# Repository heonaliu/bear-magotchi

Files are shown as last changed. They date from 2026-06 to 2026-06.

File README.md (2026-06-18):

<div align="center">

# 🌸 Bearmagotchi

A custom bear-style case tamagotchi. Made by 17 y/o Heona Liu. This was my first full on hardware project, so I'm pretty proud of myself. Every step was a learning process: from KiCad interface, PCB routing, OnShape building, to coding with Arduino IDE for firmware and designing a zine.

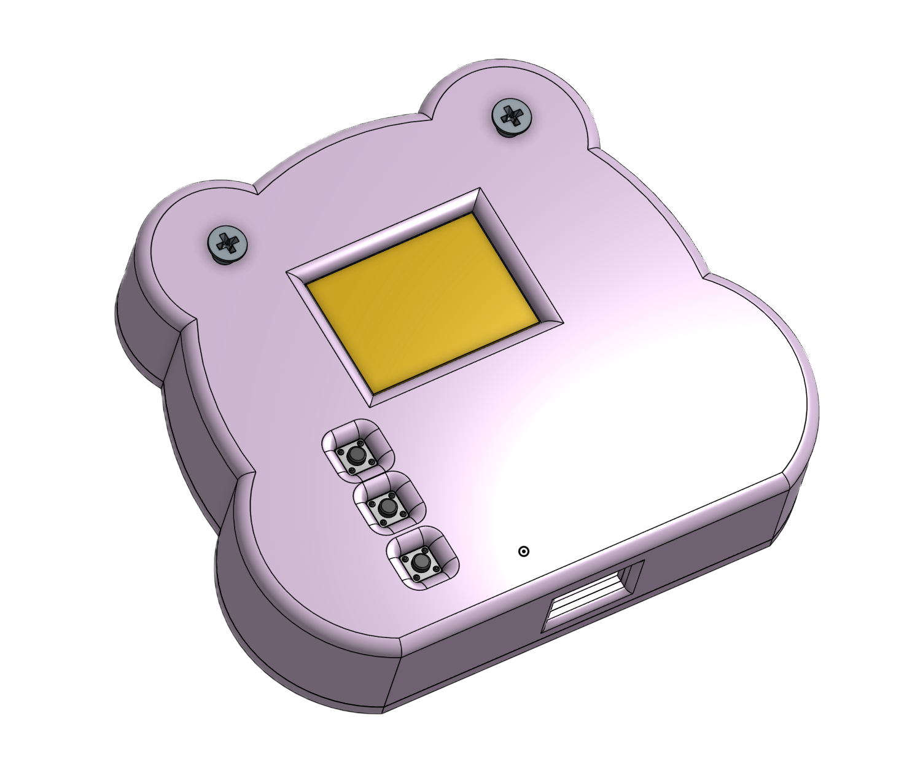
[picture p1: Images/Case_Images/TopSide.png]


This tamagotchi has 3 stats: hunger, energy, and happiness! You can play around with the different levels by using the buttons, each mapped to different functions. This was built by following [TaniWankenobi's](https://github.com/TaniWanKenobi) tamagotchi PCB tutorial. All 4 faces on the bearmagotchi are custom drawn!

## Why I Built This Project
I built this project because I have absolute 0 experience with hardware and wanted to learn! I find it so exciting to be able to design physical products! I'm more of a software person so working with hardware isn't easy for me. I procrastinated a lot because I was intimidated at first by hardware and its complexities, but I finally got the discipline and perseverance to start and finish this project. Throughout this project, I encountered many challenges and learning experiences, all which allowed me to further broaden my understanding of hardware and CAD. I also like cute things so this was a perfect project to build.

It took many trial and errors like learning how to solve DRC errors, rerouting, and being very confused at some points.

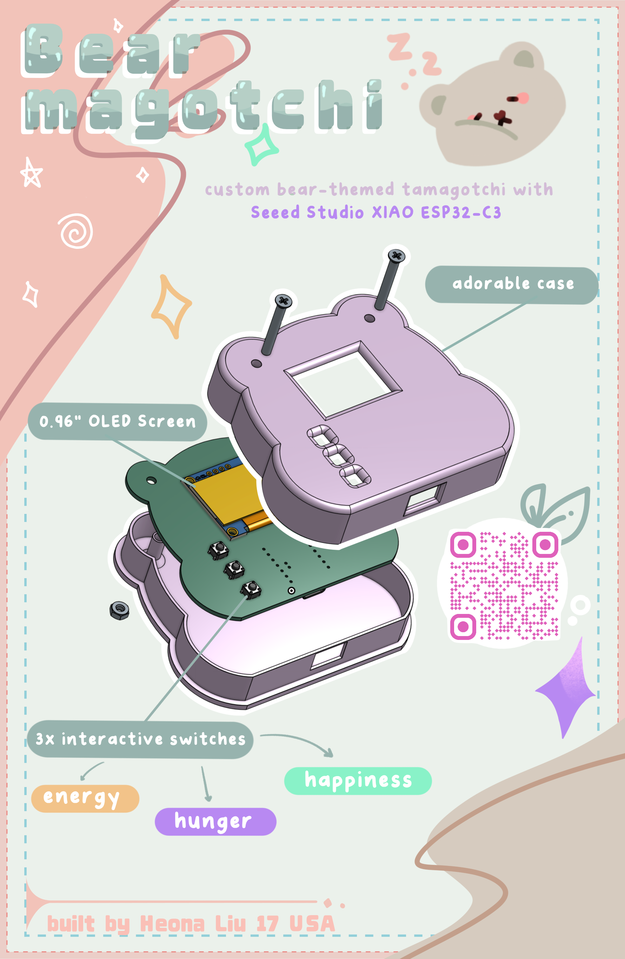
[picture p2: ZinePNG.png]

</div>

## Overview of how it works
Bearmagotchi was built with Seeed Studio XIAO ESP32-C3 and a custom PCB built with KiCad. OnShape was used to build the case design. Arduino IDE was used to code the button's functions with the OLED screen. There are three switches that you can press, which change the status of the pet's happiness, energy, and hungriness! 

### Key Parts Used:
- **Arduino MCU:** XIAO-ESP32-C3
- **Display:** 0.96" OLED screen
- **Power:** 3.7V rechargeable lithium polymer battery
- **Audio:** Buzzer -- [XHXDZ 1207-P6.5MM](https://www.lcsc.com/product-detail/C49246964.html)
- **Case:** Built with OnShape. View [Onshape CAD Link](https://cad.onshape.com/documents/021afe4b63c8b0b9c93cc183/w/f948377fc55dfd0736b0e217/e/5203c0fddfe92074836b1ae6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)
- **Firmware:** Arduino IDE in C++. Also wired and tested in a simulation in Wokwi.com. [Wokwi Link Here](https://wokwi.com/projects/467099855244316673)

- **Buzzer:** [XHXDZ 1207-P6.5MM](https://www.lcsc.com/product-detail/C49246964.html)
Switches: [BZCN TSC016A04518A](https://www.lcsc.com/product-detail/C2888493.html)
0.96" Oled Screen: [HS HS96L03W2C03](https://www.lcsc.com/product-detail/C5248080.html)

## Case Showcase
| **Top** | **Top Side View** |
| :--: | :--: |
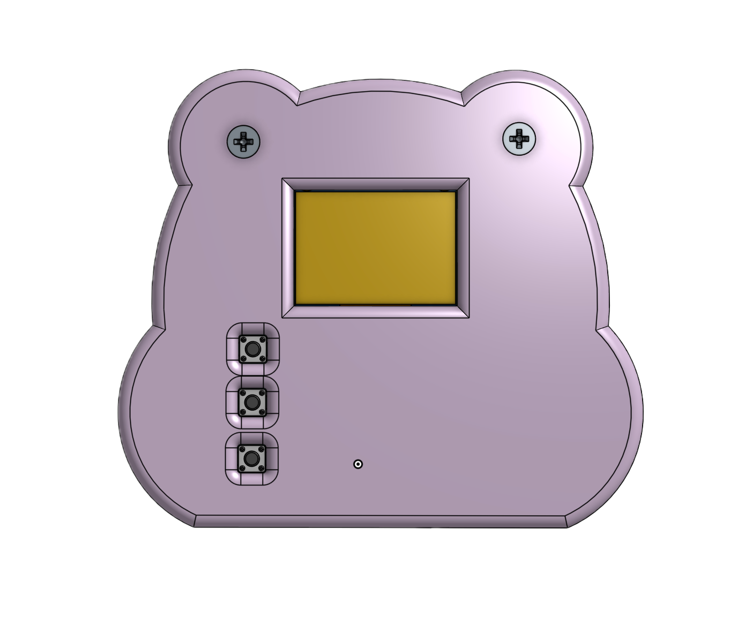
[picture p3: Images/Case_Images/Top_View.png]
|  | |
| **Bottom** | **Exploded View** |
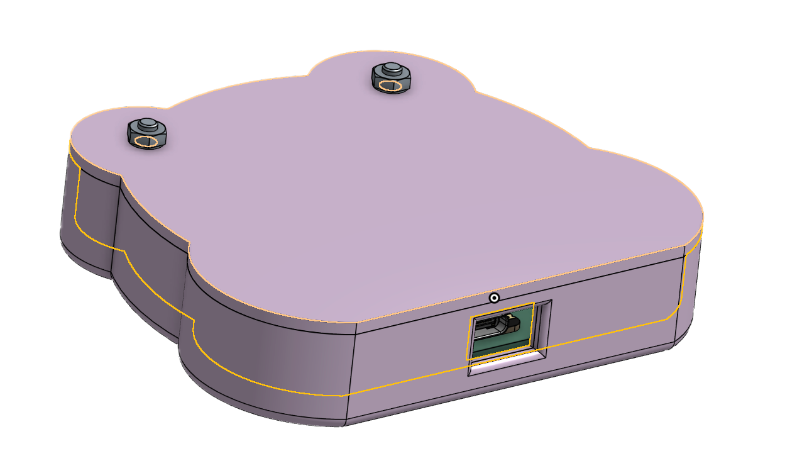
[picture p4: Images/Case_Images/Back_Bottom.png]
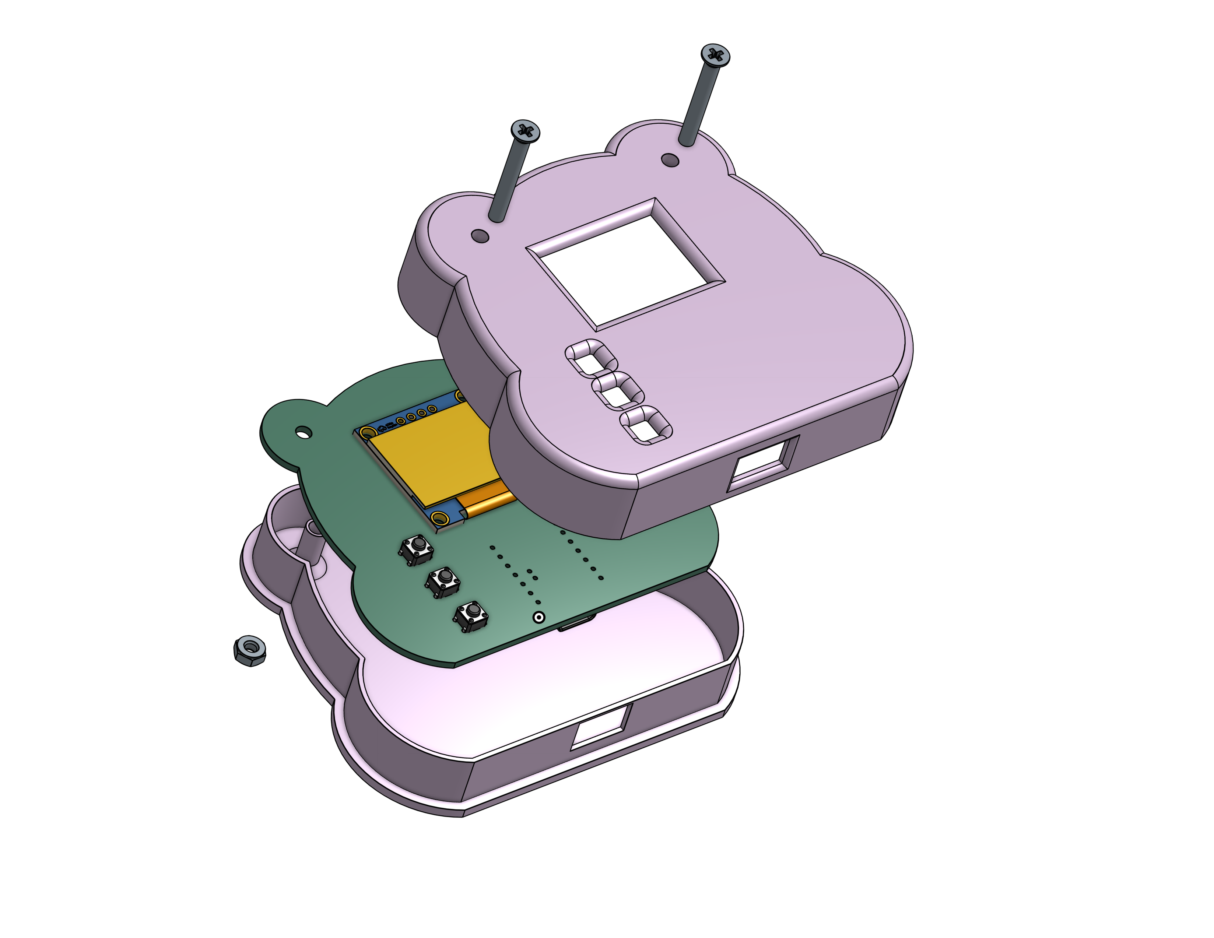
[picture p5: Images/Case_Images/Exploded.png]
|  | |

## PCB & Routing
| **Top** | **Top Routing Layer** |
| :--: | :--: |
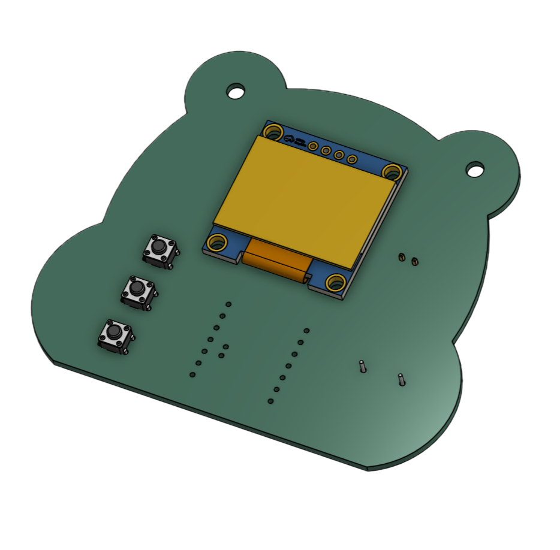
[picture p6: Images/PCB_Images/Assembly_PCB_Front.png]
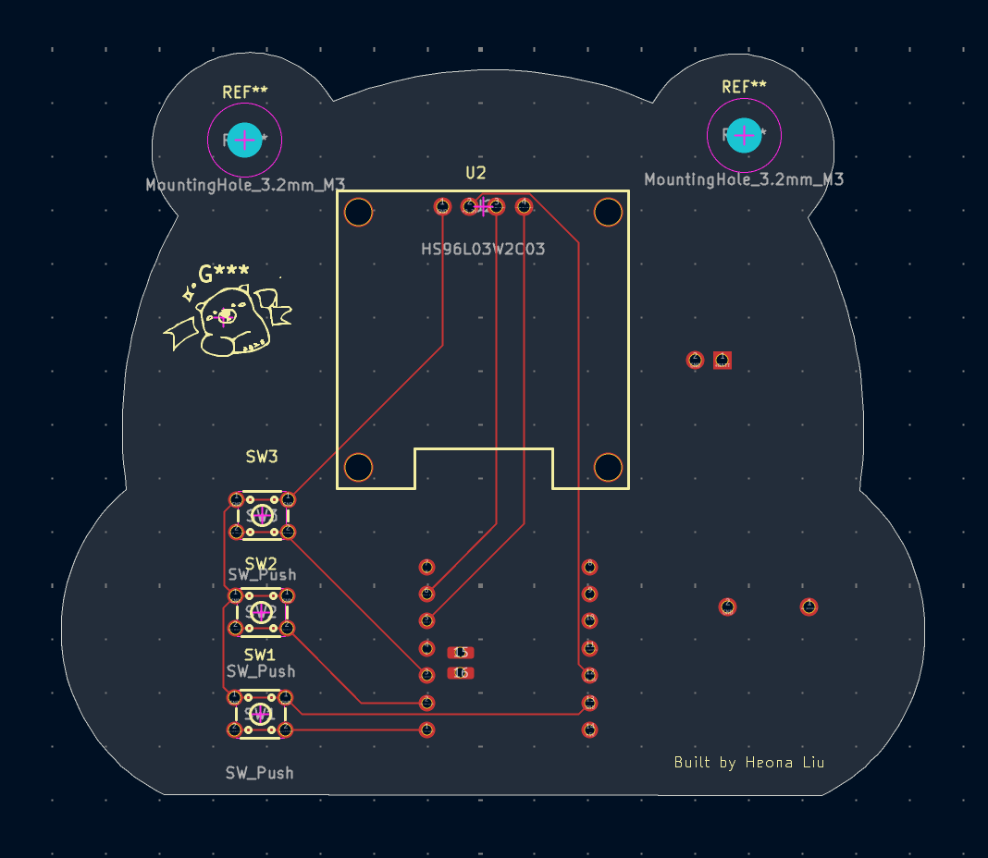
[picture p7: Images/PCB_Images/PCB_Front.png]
|  | |
| **Bottom** | **Bottom Routing Layer** |
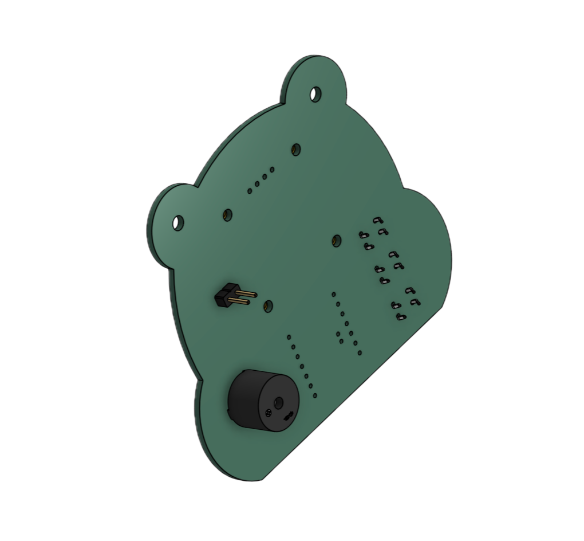
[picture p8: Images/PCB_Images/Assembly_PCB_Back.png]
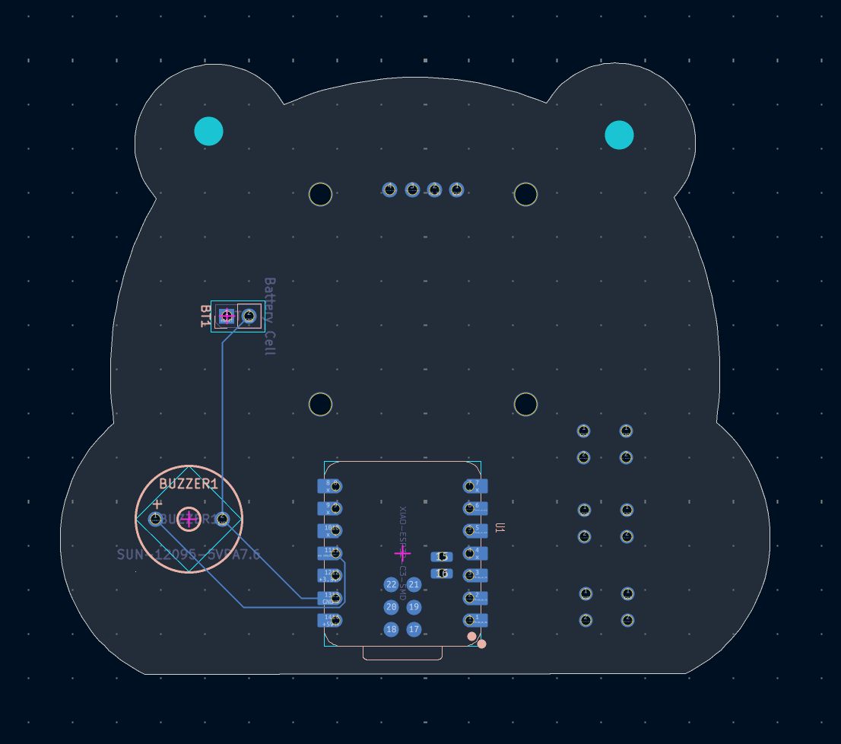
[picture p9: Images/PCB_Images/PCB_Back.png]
|  | |
|**Both**|
<div align="center">
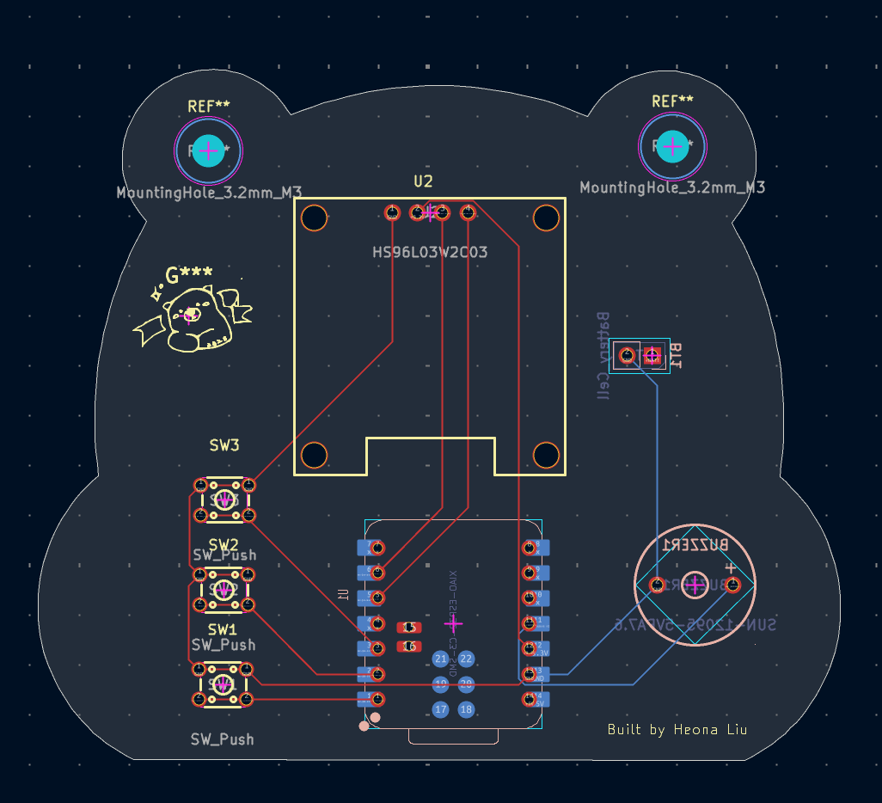
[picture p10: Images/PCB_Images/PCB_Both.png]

</div>

## Schematic
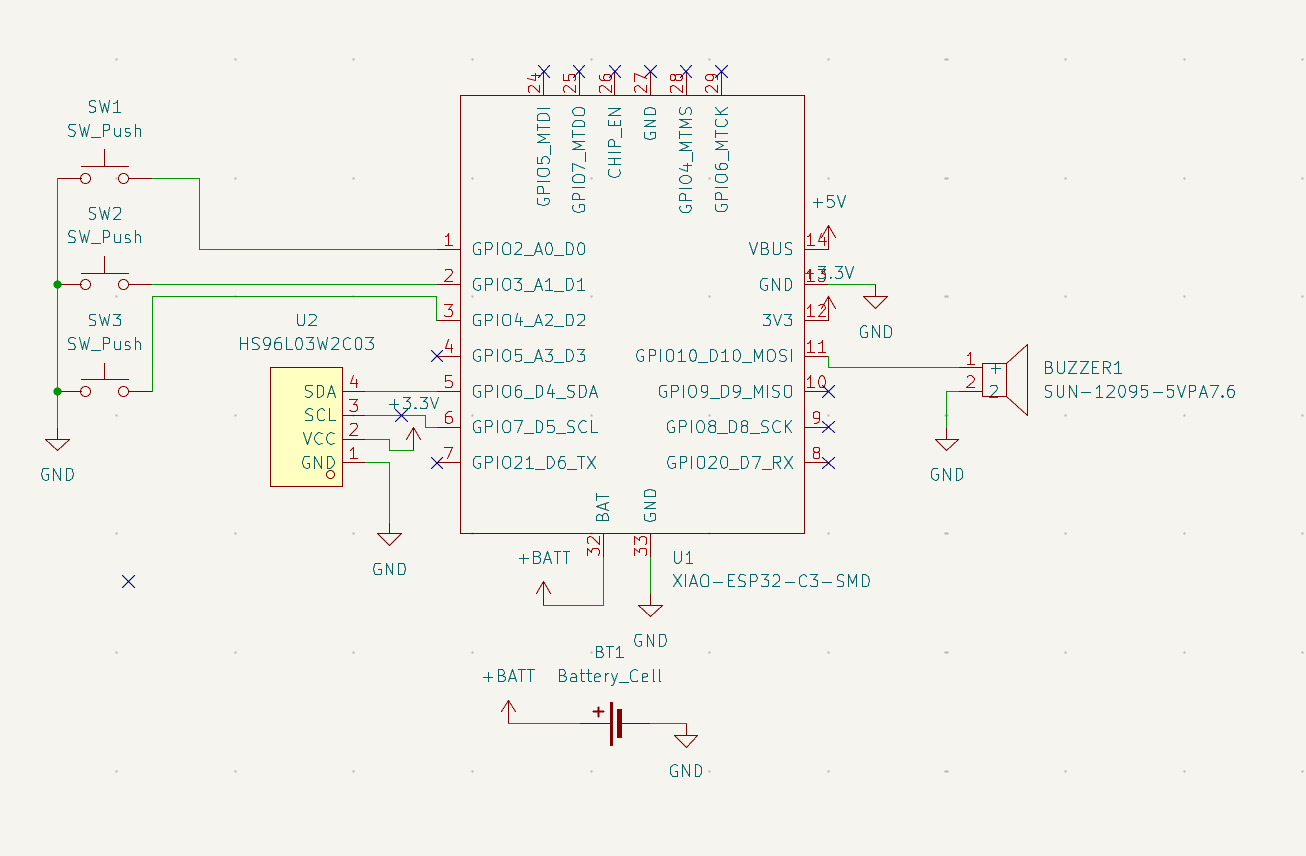
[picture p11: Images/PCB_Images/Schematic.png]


## Bill of Materials -- BOM:
| **Item** | **Description** | **Value** | **LCSC Part** | **Qty** | **MOQ** | **Total Price** | **Links** |
| :--: | :--: | :--: | :--: | :--: |:--: |:--: | :--: |
| Battery | Cell battery to power | Battery_Cell | -- | 1 | 1 | $3.37 | [Purchase Link](https://www.aliexpress.us/item/3256805856928609.html?gatewayAdapt=glo2usa4itemAdapt)
| Buzzer | Buzzer for audio | 1207-P6.5MM | C49246964 | 1 | 10 | $0.57 | [Purchase Link](https://www.lcsc.com/product-detail/C49246964.html)
| Switch | Push button | TSC016A04518A | C2888493 | 3 | 50 | $0.54 | [Purchase Link](https://www.lcsc.com/product-detail/C2888493.html)
| OLED Display | 0.96" OLED | HS96L03W2C03 | C5248080 | 1 | 1 | $2.25 | [Purchase Link](https://www.lcsc.com/product-detail/C5248080.html)
| Seeed Studio ESP32-C3 MCU | MCU Arduino board | XIAO-ESP32-C3-SMD | -- | 1 | 1 | $4.54 | [Purchase Link](https://www.aliexpress.us/item/3256806793530218.html?gatewayAdapt=glo2usa4itemAdapt)
| PCB | Main board for building | -- | -- | 1 | 1 | $4.00 | --
|PCB Shipping | To UPS Account | -- | -- | -- | -- | $2.50 | --
| **Total** |  |  |  | **8** | **64** | **$17.77** | |

## Structural (Screws, Nuts) -- BOM:
| **Item** | **Description** | **Qty**  | **Total Price** | **Link**
| :--: | :--: | :--: | :--: |:--: |
| M3 x 25mm Screw | PH Countersunk flat head screw M3x0.5 x 25 Stainless Steel  | 2 | $1.74 | [Purchase Link](https://accu-components.com/us/countersunk-socket-head-screws/5430-SSK-M3-25-A2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) |
| Hex Nut Grade A&B | M3x0.5  Stainless Steel  | 2 | $0.14 | [Purchase Link](https://belmetric.com/hex-nut-a2-stainless-din-934/?sku=NR3SS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) |
| Total | | 4 | $1.88 | |

## Step by Step Assembly
| **Bottom case** | **Place PCB on top** |
| :--: | :--: |
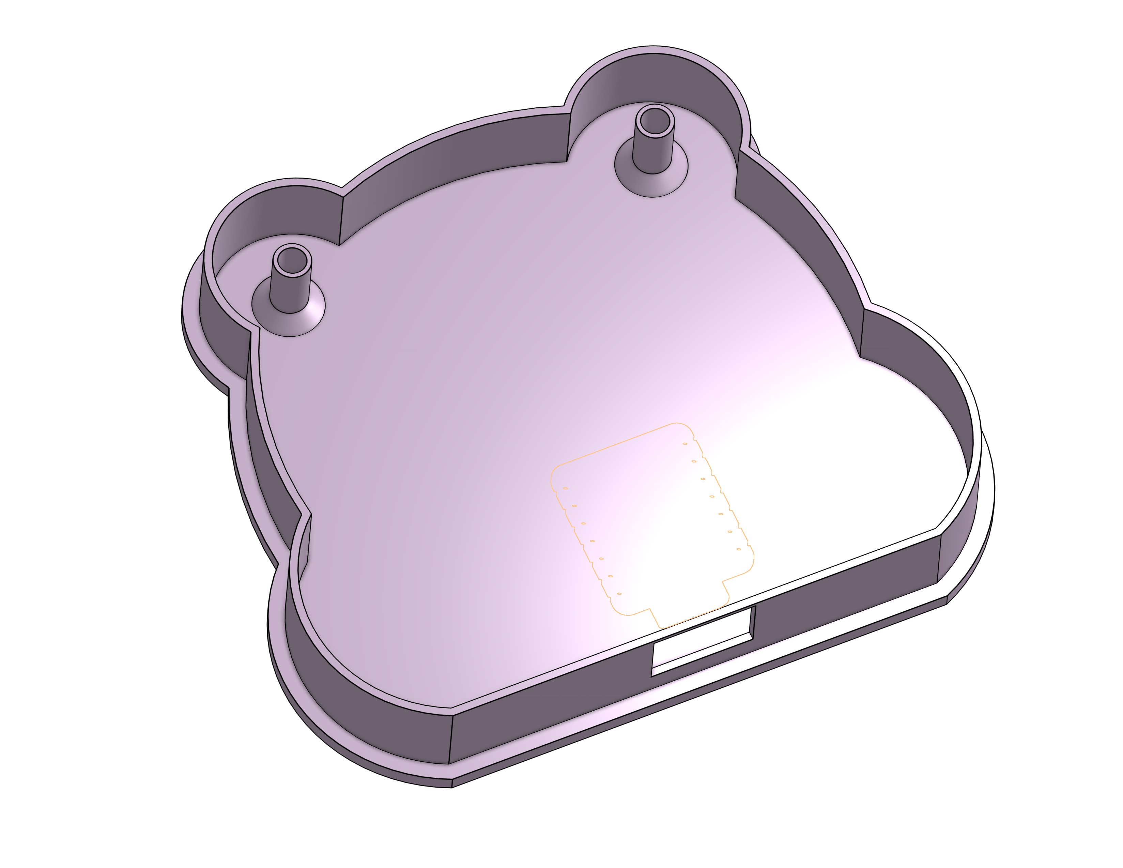
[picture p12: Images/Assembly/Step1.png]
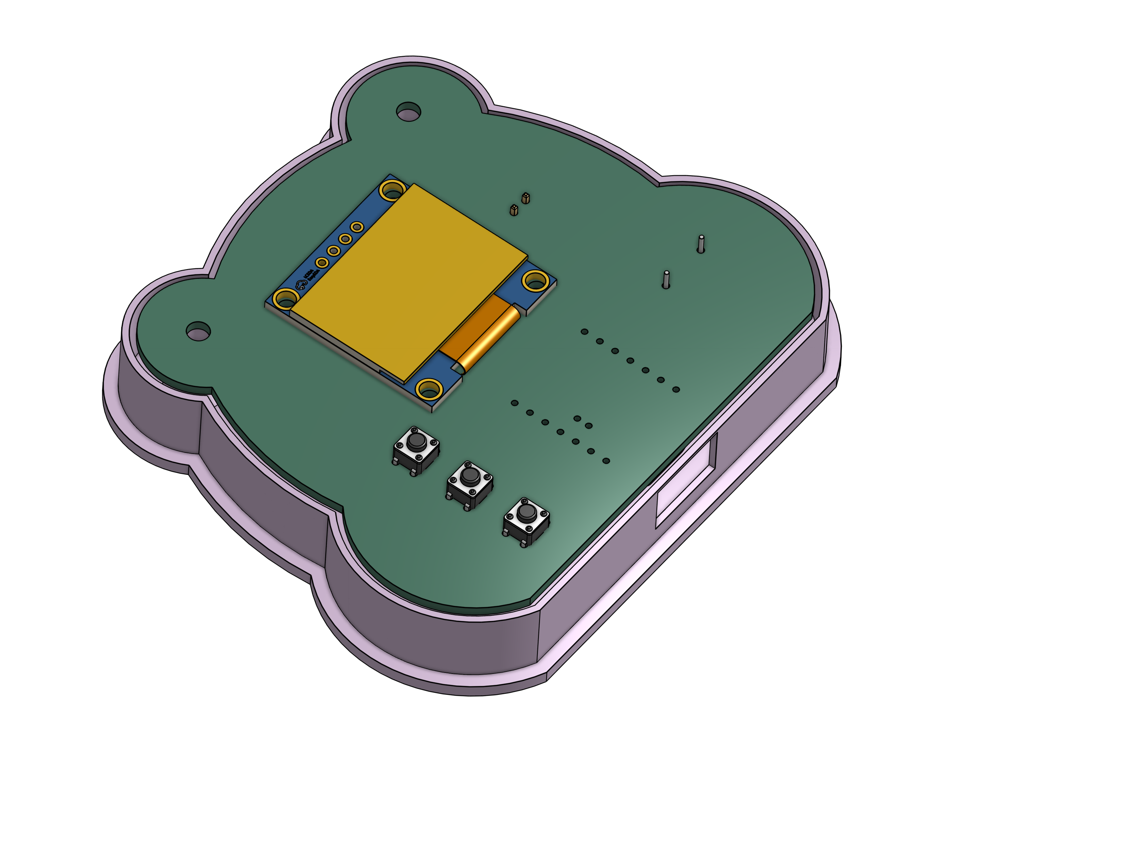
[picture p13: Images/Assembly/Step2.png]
|  | |
| **Place top cover aligned with the holes** | **Put in the M3 Screws & fasten with hex nuts** |
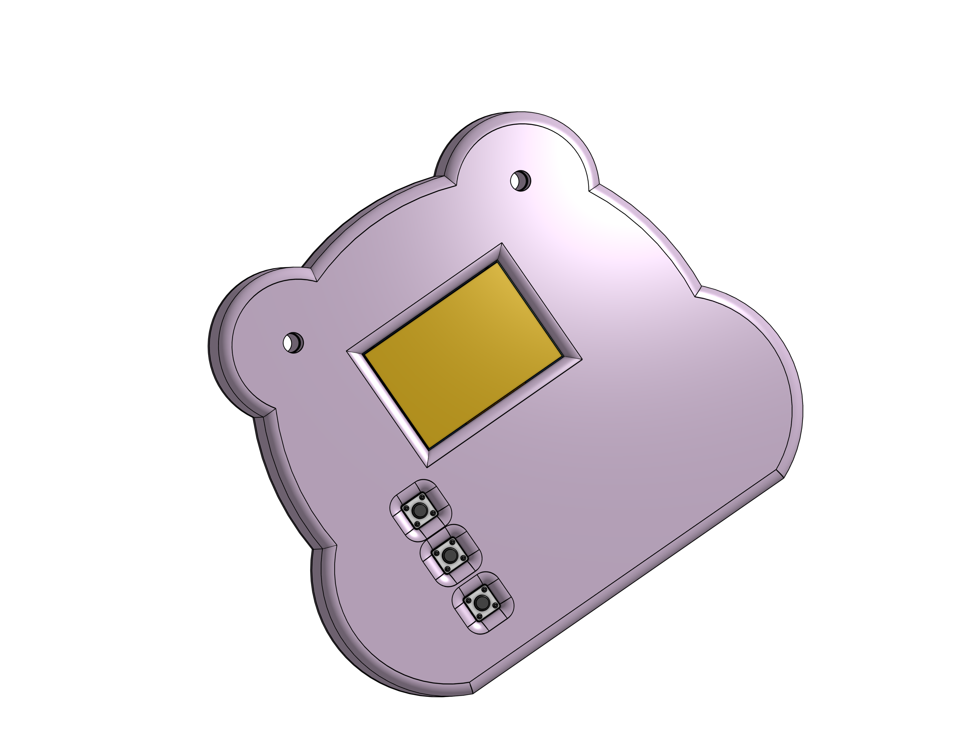
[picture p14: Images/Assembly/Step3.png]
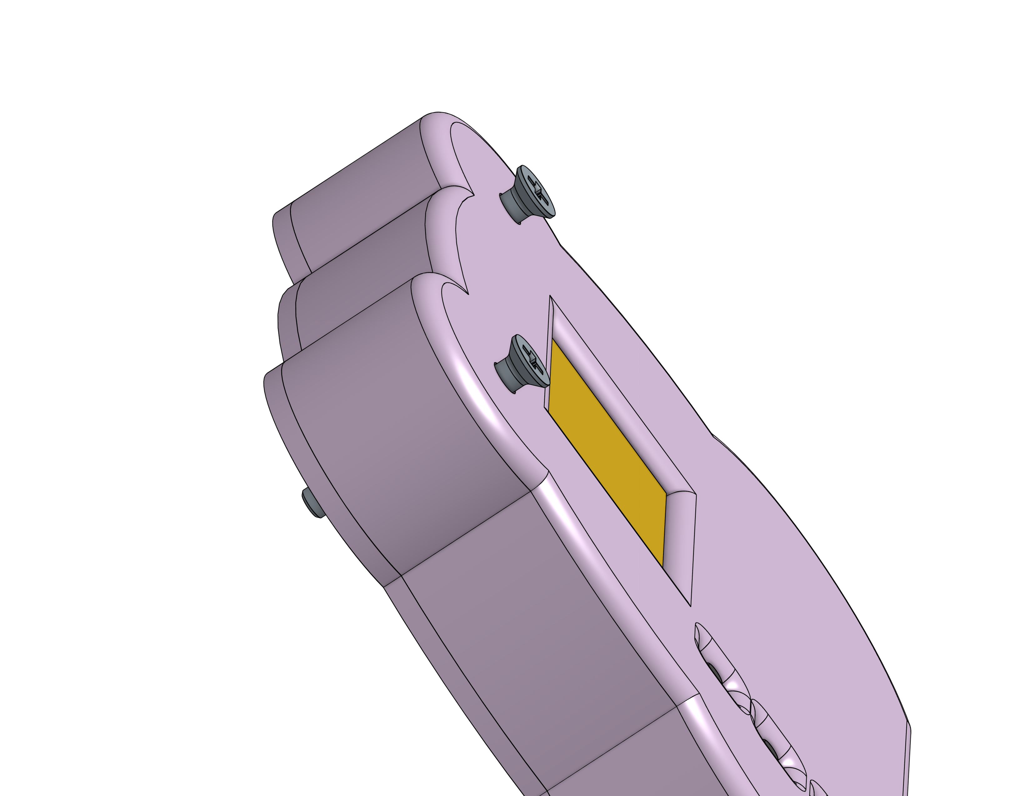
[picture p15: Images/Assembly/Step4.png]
|  | |

## Firmware
Firmware utilizes Arduino using C++, listens for button presses, and changes OLED screen accordingly.
- Top Button: (Feed) -- makes pet less hungry
- Middle Button: (Play) -- increases happiness, decreases energy
- Bottom Button: (Sleep) -- sleeping (+energy)

Check out the simulation in Wokwi.com. [Wokwi Link Here!](https://wokwi.com/projects/467099855244316673)

### Screens
| **Happy (all >50)** | **Neutral (standard)** |
| :--: | :--: |
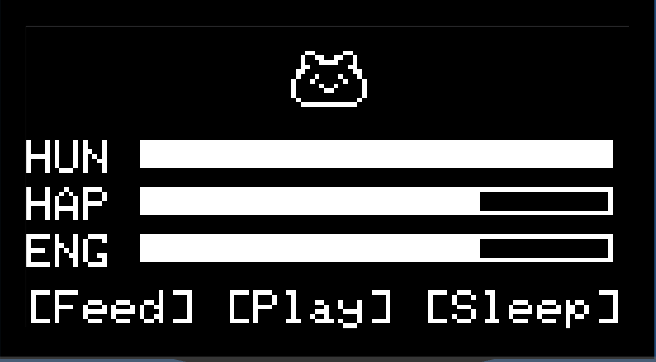
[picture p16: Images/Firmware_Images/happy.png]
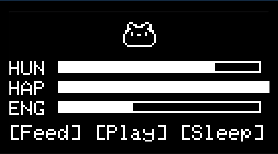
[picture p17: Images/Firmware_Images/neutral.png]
|  | |
| **Sad (a stat<30)** | **Sleep (on press)** |
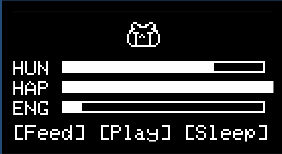
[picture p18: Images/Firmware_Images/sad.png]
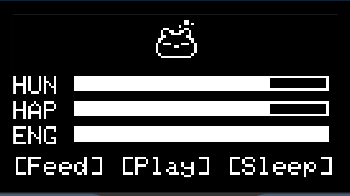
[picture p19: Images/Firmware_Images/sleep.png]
|  | |

### How to use it
1. Arduino IDE > Settings and add into Additional Boards Manager URLS `https://espressif.github.io/arduino-esp32/package_esp32_index.json` - Click OK.
2. Tools > Board > Board Manager -- search `esp32 by Espressif Systems` and install (version should be 3+).
3. Create a fresh workspace
4. Tools > Board > esp32 > XIAO ESP32C3
5. Add the following libraries from Sketch > Include Library > Manage Libraries
- Adafruit SSD1306
- Adafruit GFX Library
6. Link project to machine through the USB-C cord. 
7. Copy the content in `bear.ino` to your sketch.
8. Click verify --> Upload to build

## Credits:
- This follows the tutorial by [TaniWankenobi](https://github.com/TaniWanKenobi)
- [Case tutorial](https://www.youtube.com/watch?v=7FC-pByCCXM) (for reference) by Pcb Cupid on YouTube
- README Structure, Formating & File Organization Inspiration: [DjukicAleksej](https://github.com/DjukicAleksej)

## Software Used
- Arduino IDE
- KiCad
- OnShape
- Visual Studio Code
- Procreate
- Wokwi
---
built with <3 by Heona Liu 2026

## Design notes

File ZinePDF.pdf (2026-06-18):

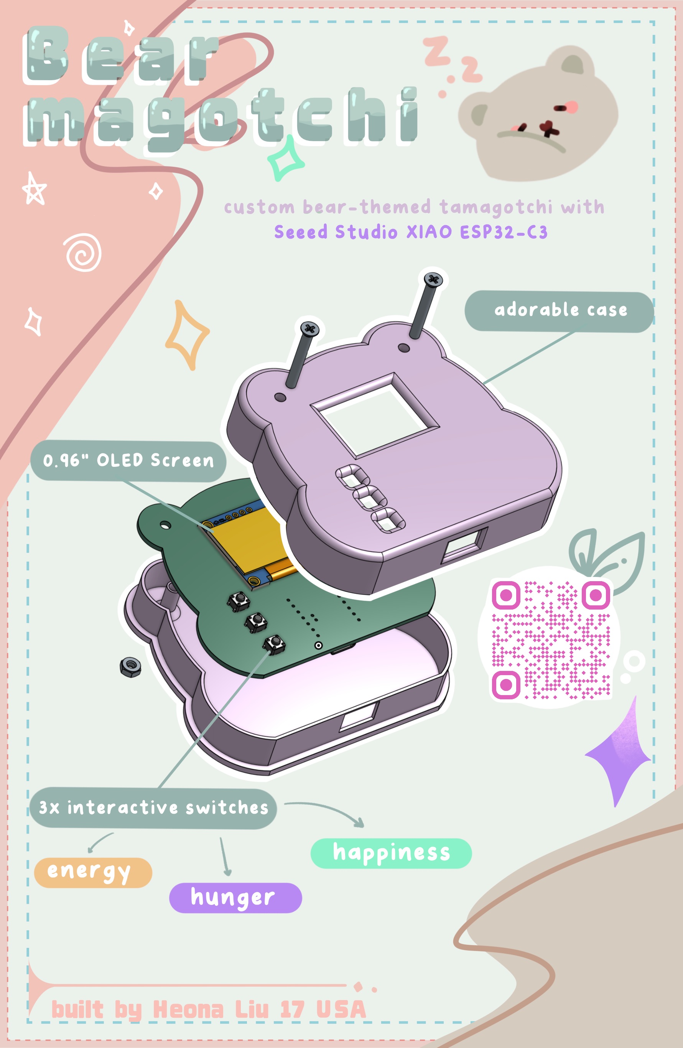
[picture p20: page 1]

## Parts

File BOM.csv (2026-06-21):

Reference | Item | Description | Value | Footprint | LCSC Part | Qty | MOQ | Total Price | Link
BT1 | Battery | Cell battery to power | Battery_Cell | Connector_PinHeader_2.54mm:PinHeader_1x02_P2.54mm_Vertical | -- | 1 | 1 | $3.37 | https://www.aliexpress.us/item/3256805856928609.html?gatewayAdapt=glo2usa4itemAdapt
BUZZER1 | Buzzer | Buzzer for audio | SUN-12095-5VPA7.6 | easyeda2kicad:BUZ-TH_BD12.0-P7.60-D0.6-FD | C49246964 | 1 | 10 | $0.57 | https://www.lcsc.com/product-detail/C49246964.html
SW1,SW2,SW3 | Switch | Push button | SW_Push | easyeda2kicad:SW-TH_4P-L4.5-W4.5-P3.00-LS4.8 | C2888493 | 3 | 50 | $0.54 | https://www.lcsc.com/product-detail/C2888493.html
U2 | OLED Display | 0.96" OLED | HS96L03W2C03 | easyeda2kicad:OLED-TH_L27.8-W27.2-P2.54_C9900033791 | C5248080 | 1 | 1 | $2.25 | https://www.lcsc.com/product-detail/C5248080.html
U1 | Seeed Studio ESP32-C3 MCU | MCU Arduino board | XIAO-ESP32-C3-SMD | New_XIAO_Series_Footprints:XIAO-ESP32-C3-DIP-SMD | -- | 1 | 1 | $4.54 | https://www.aliexpress.us/item/3256806793530218.html?gatewayAdapt=glo2usa4itemAdapt
-- | PCB | Main board for building | -- | -- | -- | 1 | 1 | $4.00 | --
-- | PCB Shipping | To UPS Account | -- | -- | -- | -- | -- | $2.50 | --
 | **Total** |  |  |  |  | 8 | 64 | $17.77

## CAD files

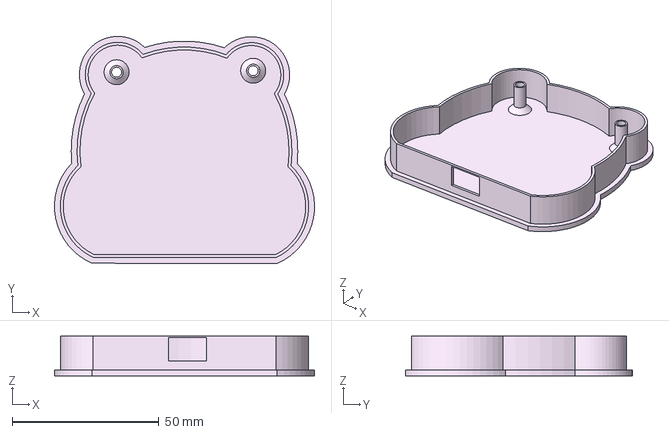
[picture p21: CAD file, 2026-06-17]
Case-Files/Bear-magotchi - Bottom-Cover.step
88.5 x 77.3 x 13.5 mm

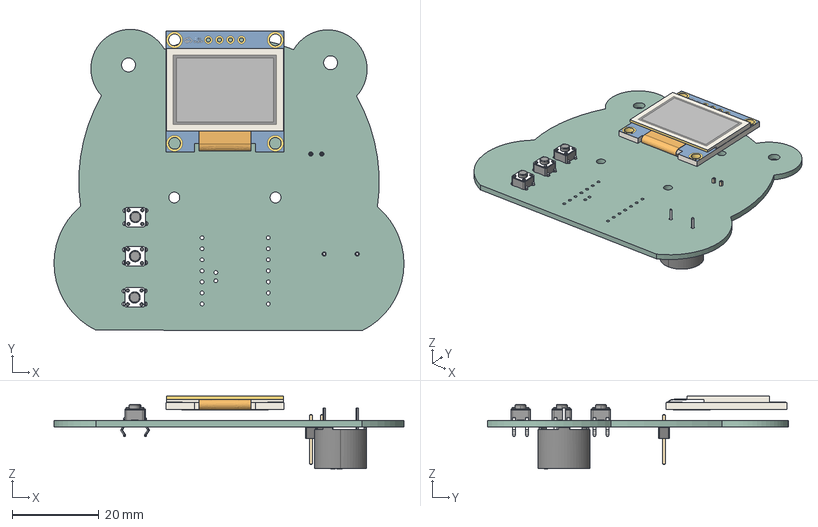
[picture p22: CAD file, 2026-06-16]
PCB/bear.step
80.5 x 69.3 x 16.7 mm
OLED-TH_L27.8-W27.2-P2.54_C9900033791
PinHeader_1x02_P2.54mm_Vertical
BUZ-TH_D12.0-H9.5-P7.60
tamagotchi_PCB

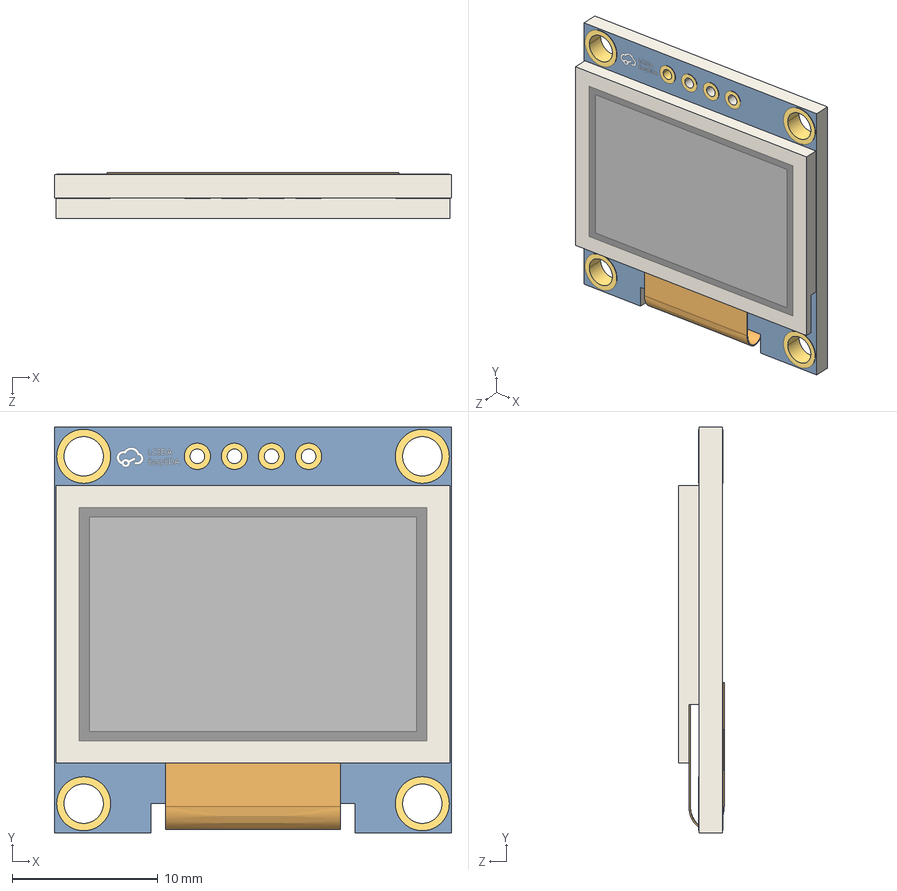
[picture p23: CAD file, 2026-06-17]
PCB/Extra Imports/3D_Model_Imports/OLED-TH_L27.8-W27.2-P2.54_C9900033791.step
27.2 x 27.8 x 3.12 mm

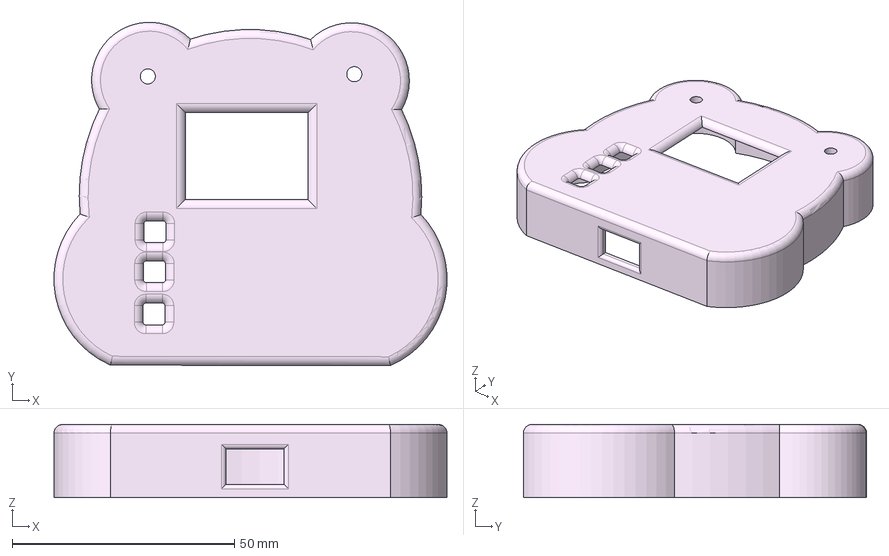
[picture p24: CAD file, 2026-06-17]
Case-Files/Bear-magotchi - Top-Cover.step
88.5 x 77.3 x 16.5 mm

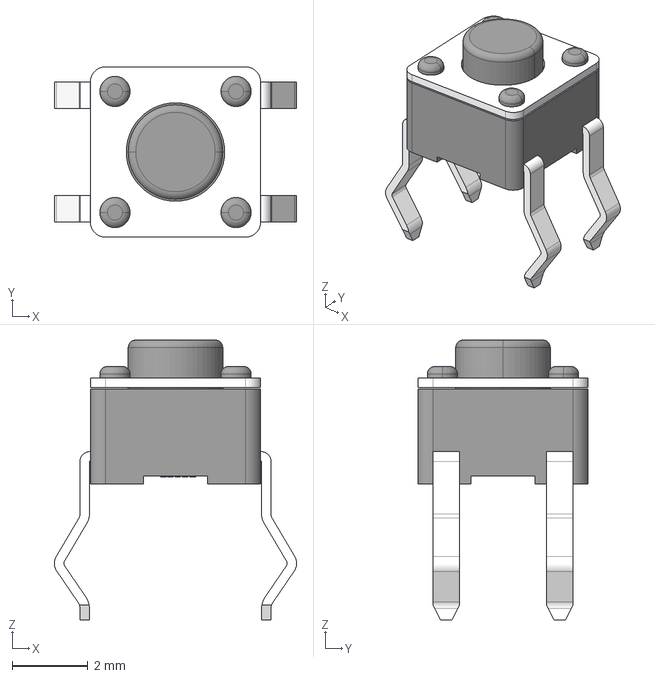
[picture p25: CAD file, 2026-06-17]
PCB/Extra Imports/3D_Model_Imports/SW-TH_4P-L4.5-W4.5-P3.00-LS4.8.step
6.40 x 4.50 x 7.40 mm

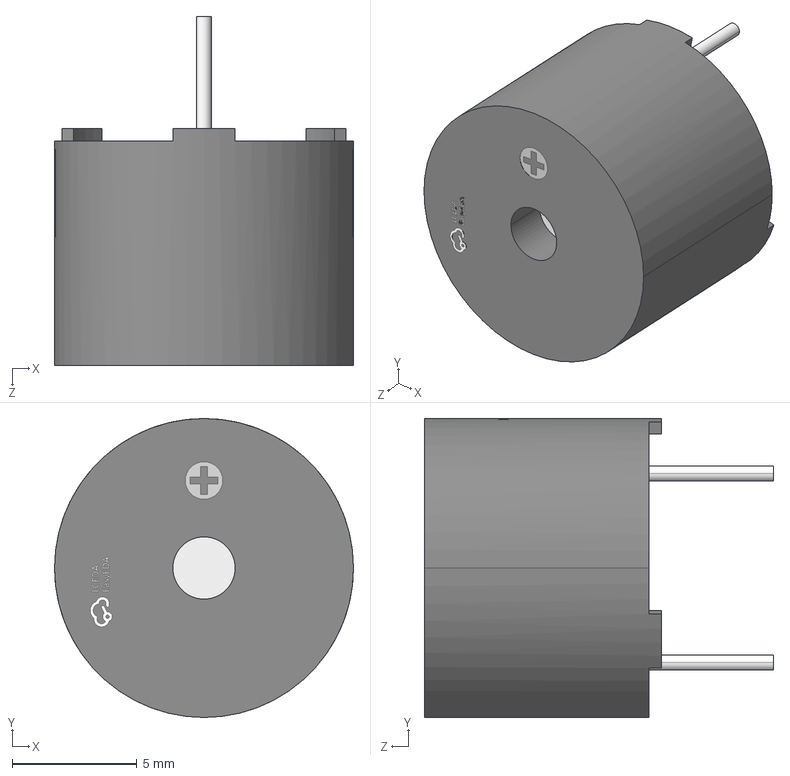
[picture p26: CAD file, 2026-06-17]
PCB/Extra Imports/3D_Model_Imports/BUZ-TH_D12.0-H9.5-P7.60.step
12.0 x 12.0 x 14.0 mm

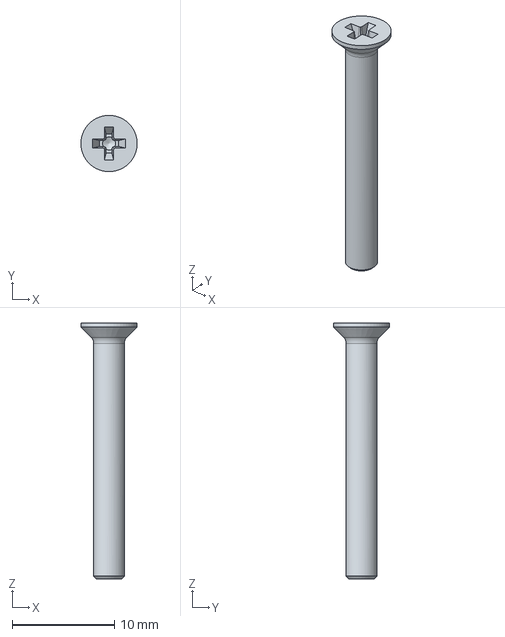
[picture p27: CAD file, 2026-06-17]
Case-Files/Components_Screws_3D-Models/PH Countersunk flat head screw M3x0.5 x 25.step
5.49 x 5.50 x 25.0 mm

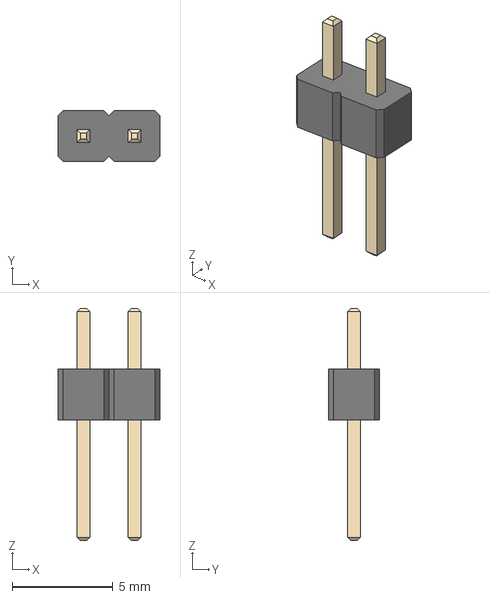
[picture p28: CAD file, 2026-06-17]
Case-Files/Components_Screws_3D-Models/PinHeader_1x02_P2.54mm_Vertical.step
5.08 x 2.54 x 11.5 mm

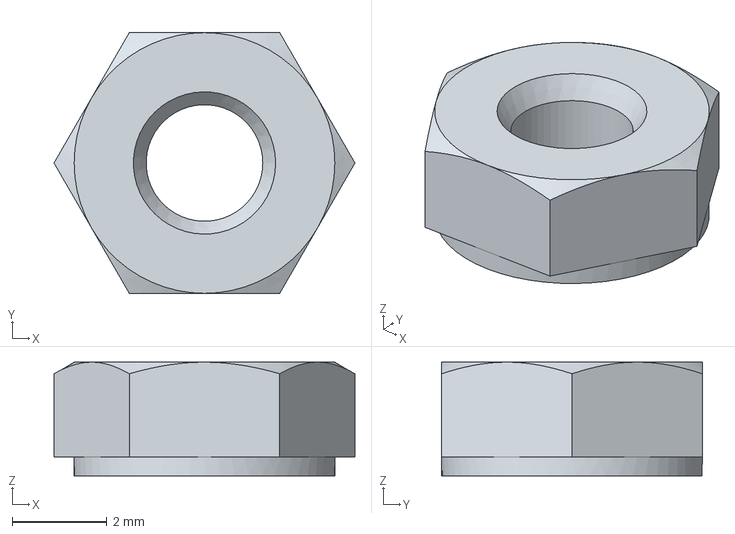
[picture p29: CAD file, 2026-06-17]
Case-Files/Components_Screws_3D-Models/Hex nut grade A & B M3x0.5.step
6.35 x 5.50 x 2.40 mm

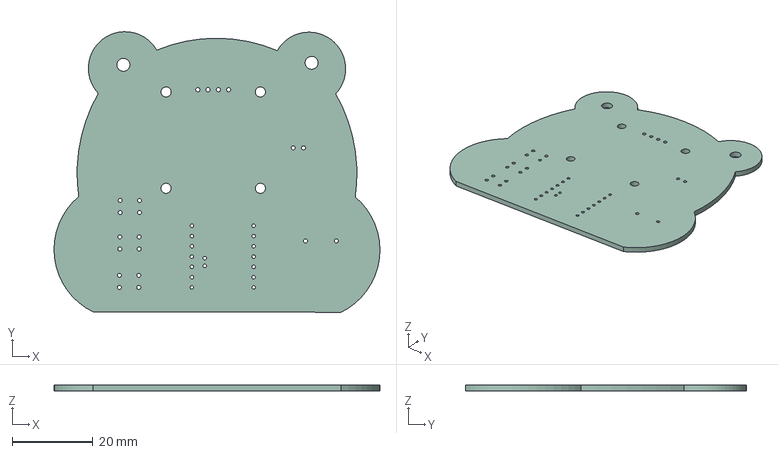
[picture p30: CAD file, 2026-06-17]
Case-Files/Components_Screws_3D-Models/3D_PCB_Model.step
80.5 x 69.3 x 1.51 mm

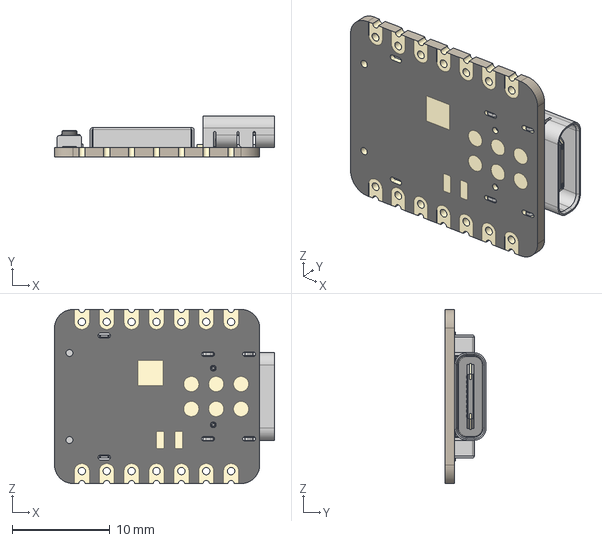
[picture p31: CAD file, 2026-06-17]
Case-Files/Components_Screws_3D-Models/XIAO-ESP32-C3.step
22.5 x 4.21 x 17.8 mm

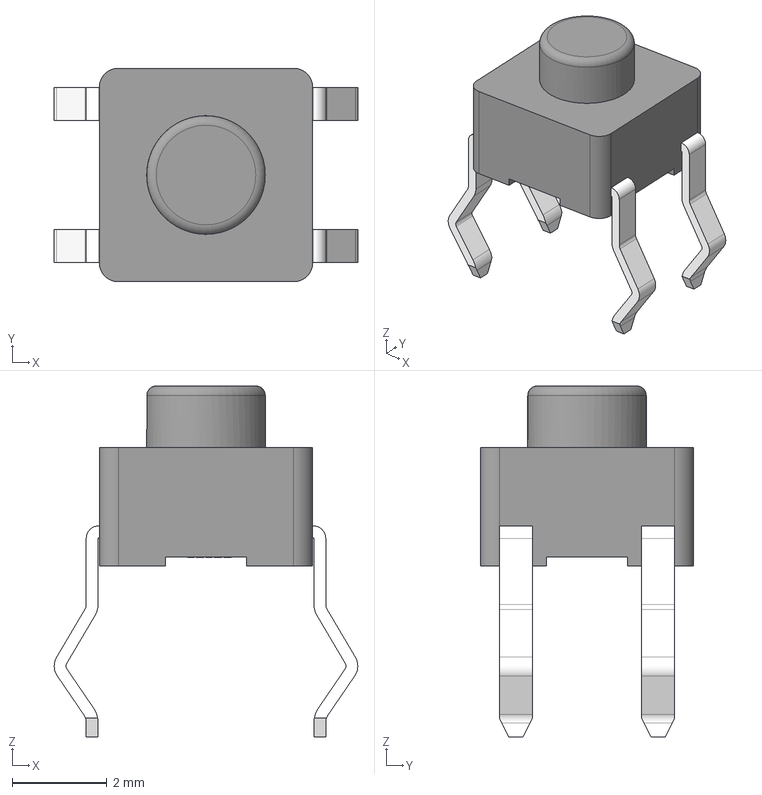
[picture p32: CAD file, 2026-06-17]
Case-Files/Components_Screws_3D-Models/SW-TH_Button.step
6.40 x 4.50 x 7.40 mm

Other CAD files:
Case-Files/Components_Screws_3D-Models/BUZ-TH_D12.0-H9.5-P7.60.step
Case-Files/Components_Screws_3D-Models/OLED-TH_L27.8-W27.2-P2.54_C9900033791.step

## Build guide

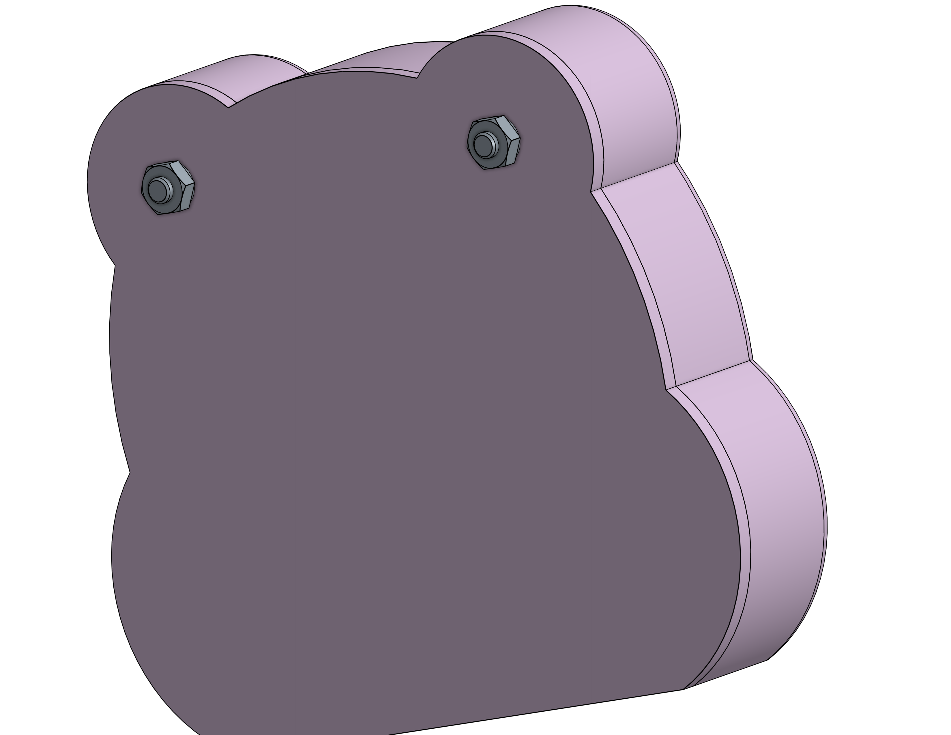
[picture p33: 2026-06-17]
Images/Assembly/Step5.png

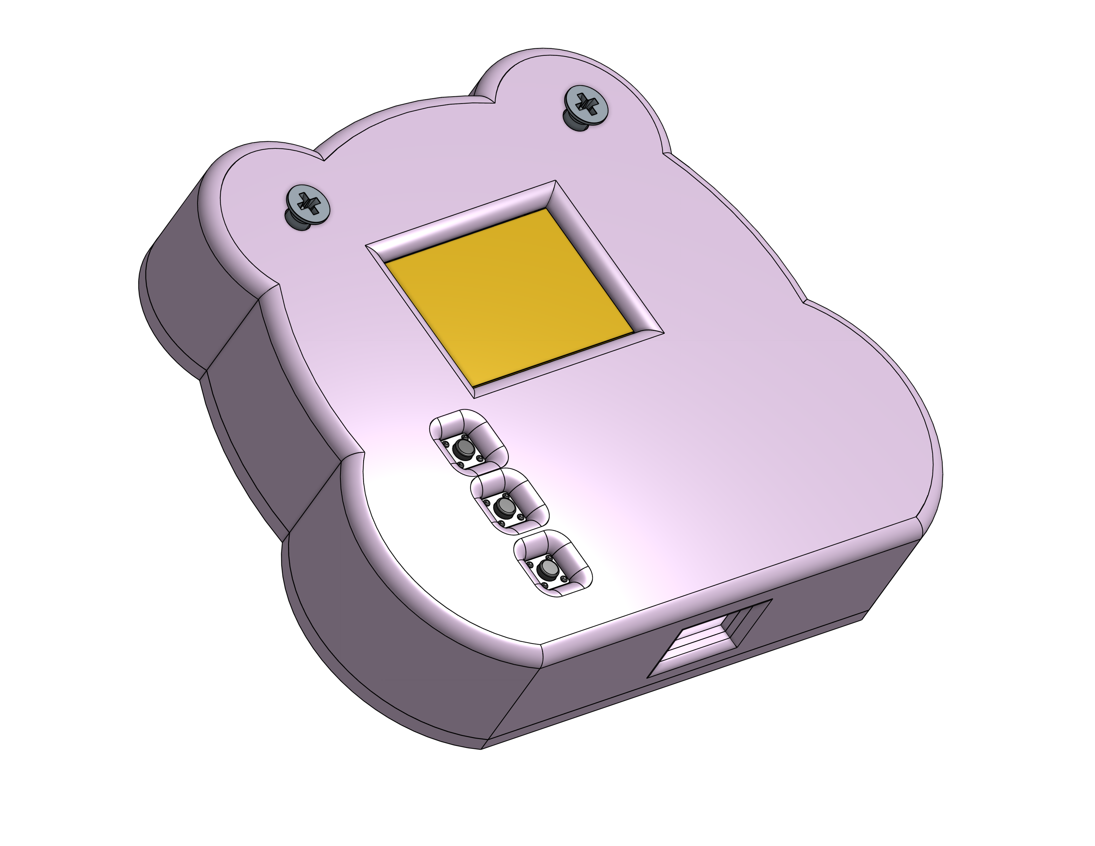
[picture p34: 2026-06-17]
Images/Assembly/Finished.png

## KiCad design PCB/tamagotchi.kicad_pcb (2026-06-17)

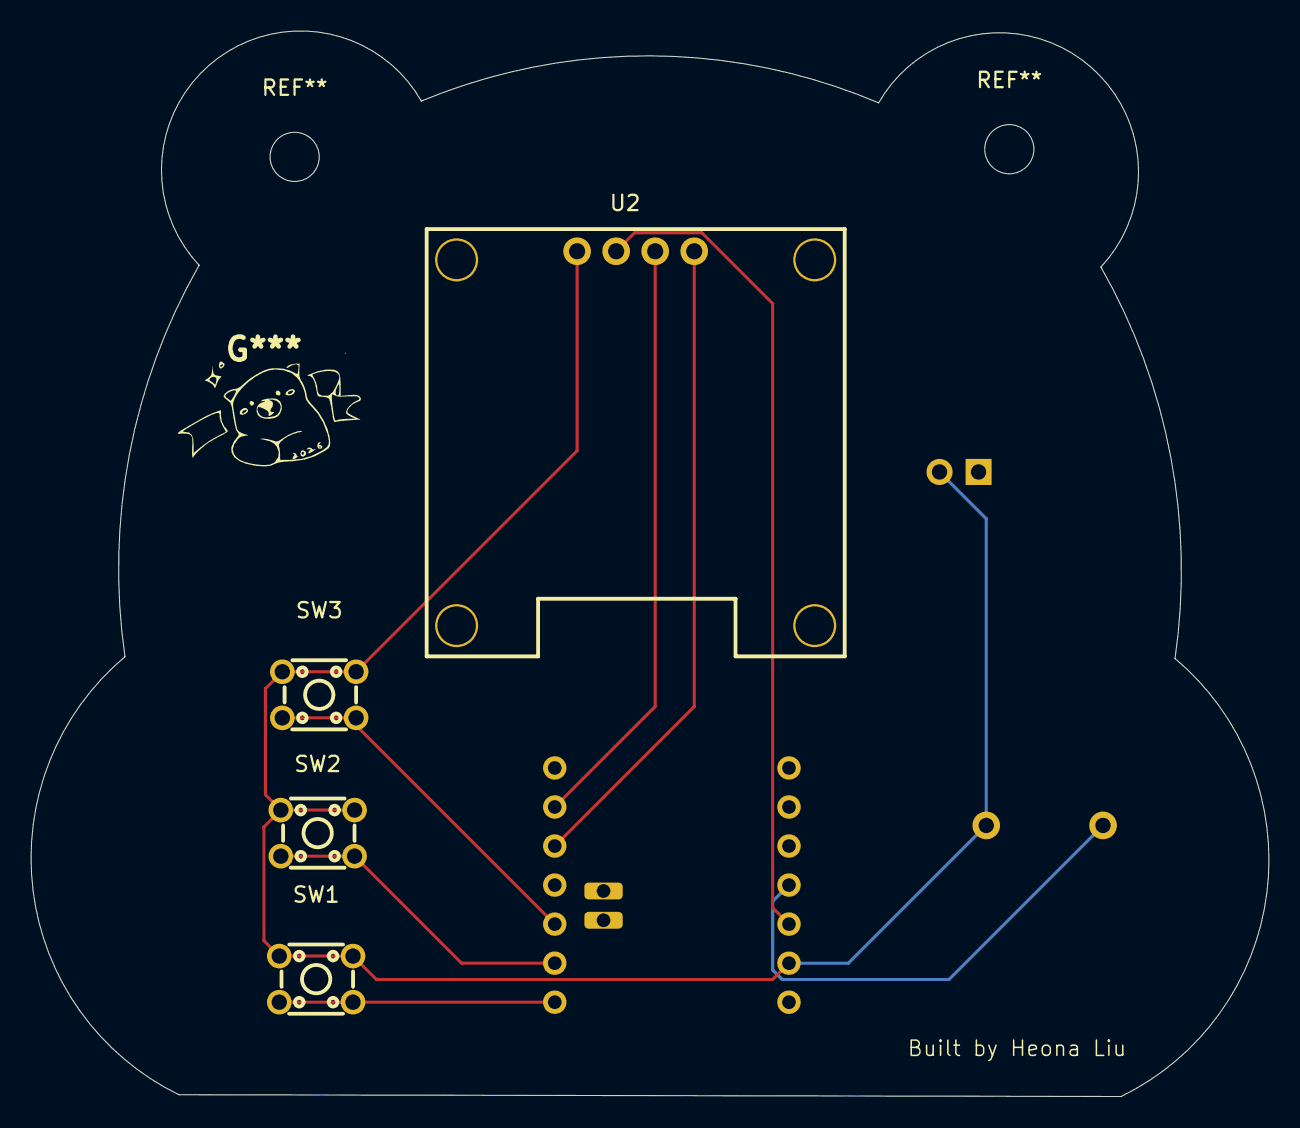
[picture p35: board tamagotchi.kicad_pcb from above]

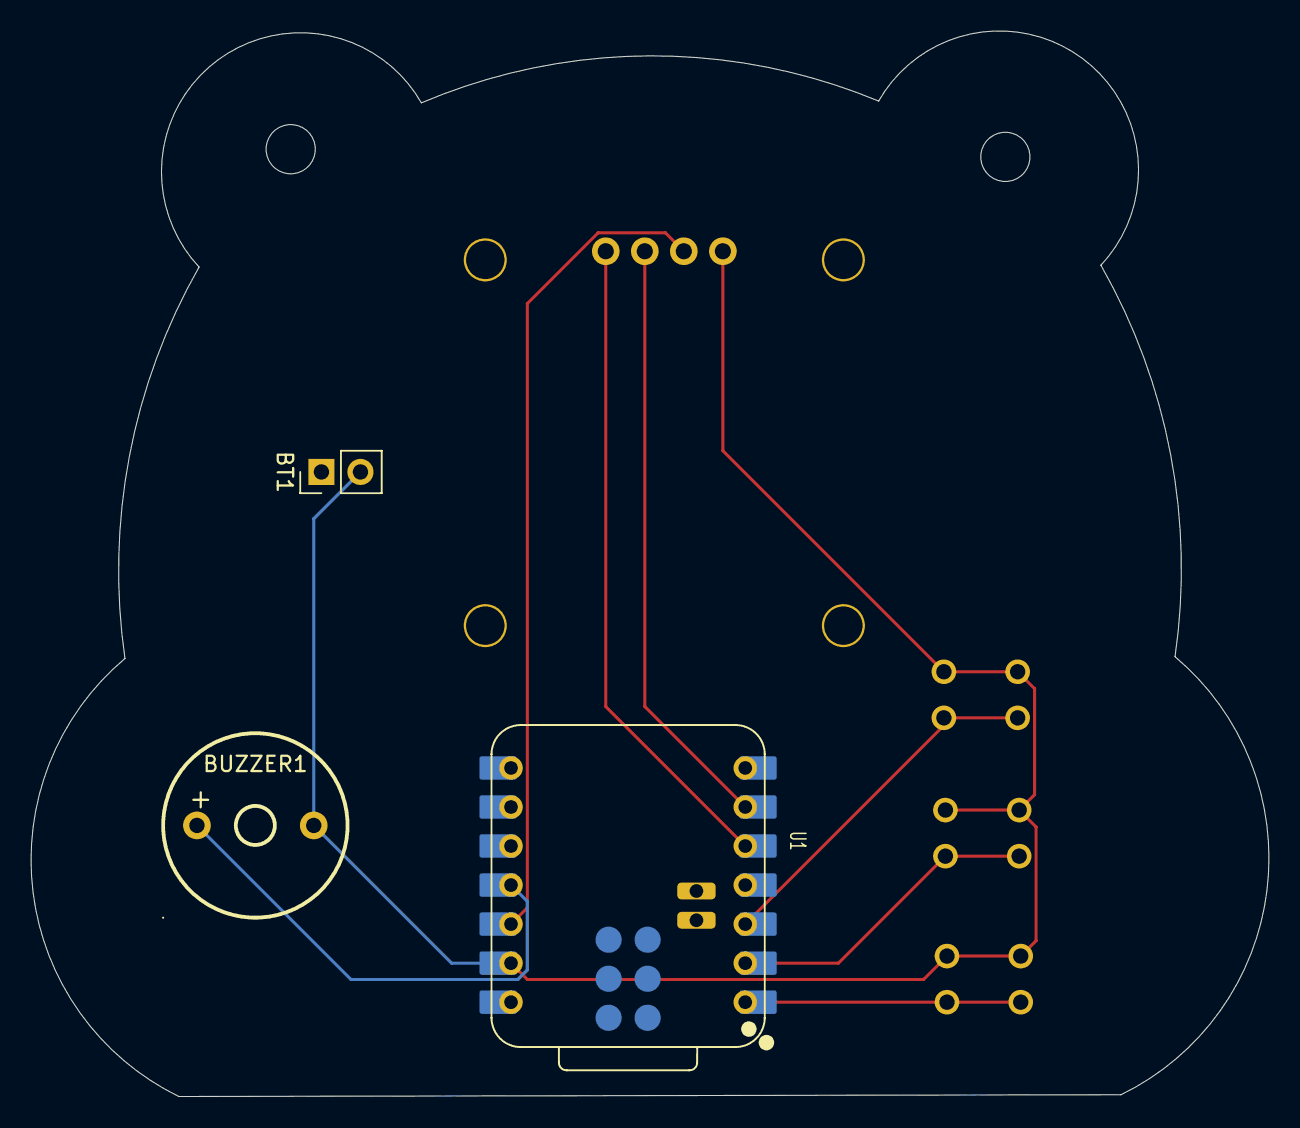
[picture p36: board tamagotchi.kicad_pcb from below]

Board: 2 copper layers, 80.5 x 69.3 mm, 7 parts (3 on the bottom side), 8 nets.

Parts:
BT1: Battery_Cell; PinHeader_1x02_P2.54mm_Vertical
BUZZER1: SUN-12095-5VPA7.6; BUZ-TH_BD12.0-P7.60-D0.6-FD
SW1, SW2, SW3: SW_Push; SW-TH_4P-L4.5-W4.5-P3.00-LS4.8
U1: XIAO-ESP32-C3-SMD; XIAO-ESP32-C3-DIP-SMD
U2: HS96L03W2C03; OLED-TH_L27.8-W27.2-P2.54_C9900033791

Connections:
+3.3V: U1.12 (3V3), U2.2 (VCC)
GND: BT1.2 (-), BUZZER1.2, SW1.1, SW2.1, SW3.1, U1.13 (GND), U2.1 (GND)
unnamed: BUZZER1.1 (+), U1.11 (GPIO10_D10_MOSI)
unnamed: SW1.2, U1.1 (GPIO2_A0_D0)
unnamed: SW2.2, U1.2 (GPIO3_A1_D1)
unnamed: SW3.2, U1.3 (GPIO4_A2_D2)
unnamed: U1.5 (GPIO6_D4_SDA), U2.4 (SDA)
unnamed: U1.6 (GPIO7_D5_SCL), U2.3 (SCL)

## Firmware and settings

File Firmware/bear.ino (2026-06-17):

// // buttons (traced from schematic)

// these aren't used in my program ----
// #define BTN1 0 // SW1 -> MCU Pin 1 -> GPIO2
// #define BTN2 1 // SW2 -> MCU Pin 2 -> GPIO3
// #define BTN3 2 // SW3 -> MCU PIN 3 -> GPIO4
// #define SCL 6 // PIN 5 GPIO06
// #define SDA 7  // PIN 6 GPIO07
// #define BUZZER 10 // PIN 11 GPIO10

// =================================
// brings in display driver and graphics functions
#include <Wire.h>
#include <Adafruit_GFX.h>
#include <Adafruit_SSD1306.h>

// 0.96" OLED resolution (128x64px)
#define SCREEN_WIDTH 128
#define SCREEN_HEIGHT 64
#define OLED_RESET -1 //reset pin for OLED

Adafruit_SSD1306 display(SCREEN_WIDTH, SCREEN_HEIGHT, &Wire, OLED_RESET);

// the way I wired was SW3 on top, SW1 on bottom
#define BTN_TOP 4
#define BTN_MIDDLE 3
#define BTN_BOTTOM 2
#define BUZZER_PIN 10

// define pet model
struct Pet {
  int hunger;
  int happiness;
  int energy;
  unsigned long age;

};

Pet pet;

enum Screen {
  SCREEN_MAIN,
  SCREEN_FEED,
  SCREEN_PLAY,
  SCREEN_SLEEP
};

// tracks the current screen
Screen currentScreen = SCREEN_MAIN;

// stores the last time pet was updated
unsigned long lastUpdate = 0; 

void updatePet() {
  if (millis() - lastUpdate > 5000) { // 5000 millisec ==> 5 sec
    pet.hunger--;
    pet.happiness--;
    pet.energy--;

    //specify conditions and not go <0
    if (pet.hunger < 0) pet.hunger = 0;
    if (pet.happiness < 0) pet.happiness = 0;
    if (pet.energy < 0) pet.energy = 0;

    pet.age += 5;
    lastUpdate = millis(); // reupdate millis
  } 
}

unsigned long lastButtonPress = 0;
void checkButtons() {
  if (millis() - lastButtonPress < 200) return; //debounce effect

  if (digitalRead(BTN_TOP) == LOW) {
    //only setting state not acting yet
    currentScreen = SCREEN_FEED;
    tone(BUZZER_PIN, 1000, 50); //(buzzer, hz, time)
    lastButtonPress = millis(); //refresh when last pressed
  }
  else if (digitalRead(BTN_MIDDLE)==LOW) {
    currentScreen = SCREEN_PLAY;
    tone(BUZZER_PIN, 1200, 50);
    lastButtonPress = millis();
  }
  else if (digitalRead(BTN_BOTTOM)==LOW){
    currentScreen = SCREEN_SLEEP;
    tone(BUZZER_PIN, 800, 50);
    lastButtonPress = millis();
  }

}

void handleScreenLogic() {
  switch(currentScreen) {
    case SCREEN_FEED:
      pet.hunger += 10;
      if (pet.hunger >100) pet.hunger = 100;
      currentScreen = SCREEN_MAIN;
      break;

    case SCREEN_PLAY:
      pet.happiness += 10;
      pet.energy -=5;
      if (pet.energy<0) pet.energy = 0;
      currentScreen = SCREEN_MAIN;
      break;

    case SCREEN_SLEEP:
      pet.energy += 15;
      if (pet.energy >100) pet.energy = 100;
      
      break;

    //main shows stats, other states do actions
    case SCREEN_MAIN:
      break;
  }
}

const unsigned char PROGMEM petHappy[] = {
  0b00000000, 0b00000000,
  0b00000000, 0b00000000,
  0b00000000, 0b00000000,
  0b00011000, 0b00011000,
  0b00100110, 0b01100100,
  0b00100011, 0b11000100,
  0b00110000, 0b00001100,
  0b01100000, 0b00000110,
  0b01000100, 0b00100010,
  0b10001000, 0b00010001,
  0b10000010, 0b01000001,
  0b10000001, 0b10000001,
  0b10000000, 0b00000001,
  0b01000000, 0b00000010,
  0b00111111, 0b11111100,
  0b00000000, 0b00000000
};

const unsigned char PROGMEM petSad[] = {
  0b00000000, 0b00000000,
  0b00000000, 0b00000000,
  0b00000000, 0b00000000,
  0b00011000, 0b00011000,
  0b00100110, 0b01100100,
  0b00100011, 0b11000100,
  0b00110000, 0b00001100,
  0b01100000, 0b00000110,
  0b01011100, 0b00111010,
  0b10001001, 0b00010001,
  0b10001010, 0b10010001,
  0b10001000, 0b00010001,
  0b10001000, 0b00010001,
  0b01001000, 0b00010010,
  0b00111111, 0b11111100,
  0b00000000, 0b00000000
};
 const unsigned char PROGMEM petNeutral[] = {
  0b00000000, 0b00000000,
  0b00000000, 0b00000000,
  0b00000000, 0b00000000,
  0b00011000, 0b00011000,
  0b00100110, 0b01100100,
  0b00100011, 0b11000100,
  0b00110000, 0b00001100,
  0b01100000, 0b00000110,
  0b01001000, 0b00010010,
  0b10001001, 0b10010001,
  0b10000000, 0b00000001,
  0b10000000, 0b00000001,
  0b10000000, 0b00000001,
  0b01000000, 0b00000010,
  0b00111111, 0b11111100,
  0b00000000, 0b00000000
};

const unsigned char PROGMEM petSleep[] = {
  0b00000000, 0b00011000,
  0b00000000, 0b00011010,
  0b00000000, 0b01000000,
  0b00011000, 0b00011000,
  0b00100110, 0b01100100,
  0b00100011, 0b11000100,
  0b00110000, 0b00001100,
  0b01100000, 0b00000110,
  0b01000000, 0b00000010,
  0b10011100, 0b00111001,
  0b10000001, 0b10000001,
  0b10000000, 0b00000001,
  0b10000000, 0b00000001,
  0b01000000, 0b00000010,
  0b00111111, 0b11111100,
  0b00000000, 0b00000000
};

void render() {
  display.clearDisplay();
  const unsigned char* sprite;

  if (currentScreen == SCREEN_SLEEP) {
    sprite= petSleep;
  } else if (pet.hunger < 30 || pet.happiness < 30 || pet.energy < 30) {
    sprite = petSad;
  } else if (pet.hunger > 50 && pet.happiness >50 && pet.energy > 50) {
    sprite = petHappy;
  } else {
    sprite = petNeutral;
  }

  //draw pet sprite
  display.drawBitmap(56, 2, sprite, 16,16, SSD1306_WHITE);
  display.setTextSize(1);
  display.setCursor(0,24);
  display.print("HUN ");
  drawBar(24, 24,pet.hunger);

  display.setCursor(0,34);
  display.print("HAP ");
  drawBar(24, 34, pet.happiness);

  display.setCursor(0,44);
  display.print("ENG ");
  drawBar(24, 44, pet.energy);

  display.setCursor(0,56);
  display.println("[Feed] [Play] [Sleep]");

  display.display();
}

void drawBar(int x, int y, int value) {
  int barWidth = 100;
  int barHeight = 6;
  int fillWidth = map(value, 0,100,0, barWidth);

  display.drawRect(x,y,barWidth,barHeight,SSD1306_WHITE); //outline
  display.fillRect(x,y, fillWidth, barHeight,SSD1306_WHITE); //filled portion
}


void setup() {

  Wire.begin(6,7);

  pinMode(BTN_TOP, INPUT_PULLUP);
  pinMode(BTN_MIDDLE, INPUT_PULLUP);
  pinMode(BTN_BOTTOM, INPUT_PULLUP);
  pinMode(BUZZER_PIN, OUTPUT);
  
  //init oled
  display.begin(SSD1306_SWITCHCAPVCC, 0x3C);
  display.clearDisplay();
  display.setTextSize(1);
  display.setTextColor(SSD1306_WHITE);  //drawing color
  display.setCursor(0,0);
  display.println("Tamagotchi Init...");
  display.display(); // must call if want anything to appear
  delay(1000);

  pet.hunger = 80;
  pet.happiness = 80;
  pet.energy = 80;
  pet.age = 0;
}

void loop() {
  checkButtons(); // read input
  updatePet();
  handleScreenLogic();
  render();
  delay(100);
}

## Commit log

2026-06-16 update files - remove unecessary ones
    [bear.step]
2026-06-17 add assembly .step file from onshape
2026-06-17 add Top and Bottom .step covers from onshape
    [Bear-magotchi - Bottom-Cover.step, Bear-magotchi - Top-Cover.step]
2026-06-17 add component and screw files
    [3D_PCB_Model.step, BUZ-TH_D12.0-H9.5-P7.60.step, Hex nut grade A & B M3x0.5.step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]
2026-06-17 add BOM csv file
2026-06-17 track PCB files
2026-06-17 add PCB files
    [bear.step, tamagotchi.kicad_pcb, tamagotchi.kicad_sch]
2026-06-17 add 3d models and symbol libraries via upload
    [BUZ-TH_D12.0-H9.5-P7.60.step, OLED-TH_L27.8-W27.2-P2.54_C9900033791.step, SW-TH_4P-L4.5-W4.5-P3.00-LS4.8.step]
2026-06-17 add pcb 3d model
2026-06-17 add Assembly images via upload
2026-06-18 upload BOM
    [BOM.csv]
2026-06-18 write README, add BOM, add description
2026-06-18 add assembly section
2026-06-21 move BOM outside into root folder
    [BOM.csv]
